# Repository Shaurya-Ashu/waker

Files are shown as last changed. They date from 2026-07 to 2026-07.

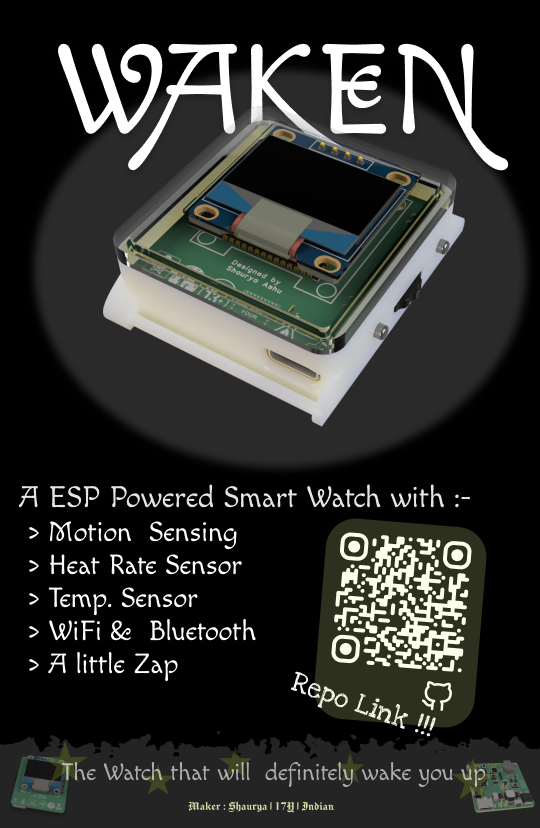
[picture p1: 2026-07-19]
IMG/Frame 7.png

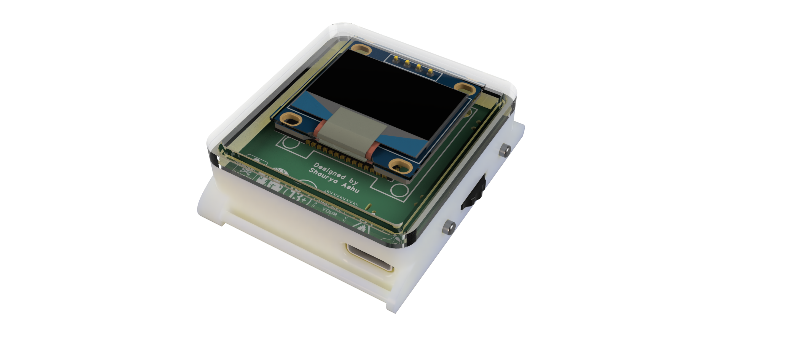
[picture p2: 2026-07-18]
CAD/IMG_1.png

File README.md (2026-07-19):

# waken
A ESP powered Smart watch which gives you a little zap to wake you up silently without disturbing anyone around you.

# why I built it ?
Ahhhh! I'm not crazy, I just sleep like a stone . So to get me up on time, I caught an idea why not make a watch which sits on my wrist and give me a little zap of 400V (\j) to wake me up . 

# Zine

 Frame 7

# Shematics 
I've used EasyEDA for design designing this project

Screenshot 2026-07-18 at 12 30 59 AM

 It has ESP32S3-WROON-1-N16R8 as the main brains , it has been built RTC and feature both Wi-Fi and Bluetooth with access to multiple GPIOs .

 Screenshot 2026-07-19 at 11 32 55 PM

 For tracking motion and physical activities like step count, etc. I've used MPU6500 which features both I2C & SPI interface. I've used I2C interface for this project.
 
Screenshot 2026-07-19 at 11 33 51 PM

 For sensing temperature I used MCP9808 which also offers I2C interface so its easy to wire all of them in signle bus 

 Screenshot 2026-07-19 at 11 35 23 PM

 The heart rate sensor is MAX30101 with I2C interface which offers optical pulse oximetry and heart-rate sensing .

 Screenshot 2026-07-19 at 11 37 22 PM

 To charge the lipo battery i have integrated a charging ic for 1s lipo and also integrated a load sharing circuit so that i can use teh device while charging .

 Screenshot 2026-07-19 at 11 39 22 PM

 To provide a constant supply of 3.3 V I am integrated a buck boost converter output of 3.3V @1.5A 
 
 Screenshot 2026-07-19 at 11 41 27 PM

 Now for that little zap i have used a simple fly back circuit with a couple inductor of scale 1:100 and IRLR7843 N chaneel mosfet to turn it on and off and a some massive 400v rated caps to store the build up with a series resistance of 150K ohm for safety .
 
 Screenshot 2026-07-19 at 11 44 28 PM

For Inputs and outputs we have 2 push buttons and a side scroll wheel with oled and buzzers as our output 

Screenshot 2026-07-19 at 11 46 19 PM

# PCB 
 I have used 4 layer configuration

Top layer:- signals and some components

Screenshot 2026-07-18 at 7 22 29 PM

First inner layer:- ground

Screenshot 2026-07-18 at 7 22 35 PM

Second inner layer:- VCC

Screenshot 2026-07-18 at 7 22 40 PM

Bottom layer:- signal and all other components

Screenshot 2026-07-18 at 7 22 23 PM

Important Note : I have not connected the ground of flyback with the rest of the circuit I will use a physical wire to connect when I receive a PCB.

FRONT

BACK

# CAD 

I have used fusion 360 student edition for designing the 3D case for this watch

It is a very simple case on which the PCB is screwed using two screws, and the top part is tucked in and glued 


# Assembly

Top Case

The pcb is screwed in 

1 step

# Firmware 
 I stated a very brief sample test code till now. When I will receive my PCB, then I will work on the rest of the firmware.

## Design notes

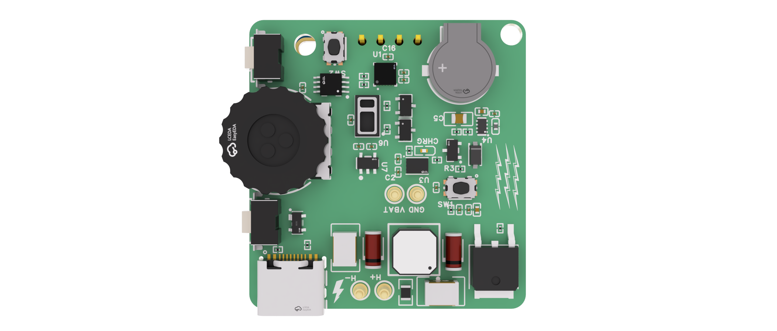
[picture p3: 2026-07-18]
CAD/BACK.png

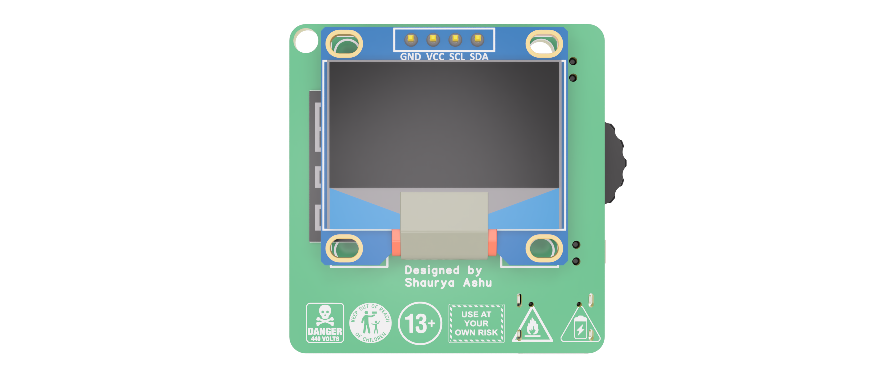
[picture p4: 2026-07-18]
CAD/FRONT.png

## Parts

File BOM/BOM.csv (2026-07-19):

S.No | Item Name | Description | Quantity | Price per Unit ($) | Total Price ($) | Purchase Link
1 | ESP32S3 | ESP32-S3-WROOM-1-N16R8 (WIRELM-SMD_ESP32-S3-WROOM-1) - Designators: BRAINS | 1 | 0.8198 | 0.8198 | https://jlcpcb.com/parts/componentSearch?searchTxt=C2913202
2 | MLT-9032 | MLT-9032 (BUZ-SMD_MLT-9032) - Designators: BUZZER1 | 1 | 0.0482 | 0.0482 | https://jlcpcb.com/parts/componentSearch?searchTxt=C194480
3 | 4.7uF | JDK063BBJ475MV-AT (C0201) - Designators: C1,C2,C13,C14 | 4 | 0.0093 | 0.0372 | https://jlcpcb.com/parts/componentSearch?searchTxt=C2880368
4 | 1uF | CL03A105MQ3CSNH (C0201) - Designators: C3 | 1 | 0.0010 | 0.0010 | https://jlcpcb.com/parts/componentSearch?searchTxt=C53067
5 | 22uF | JDK105CBJ226MV-F (C0402) - Designators: C4,C6 | 2 | 0.0245 | 0.0490 | https://jlcpcb.com/parts/componentSearch?searchTxt=C385994
6 | 47uF | GRM21BR60J476ME15L (C0805) - Designators: C5 | 1 | 0.0478 | 0.0478 | https://jlcpcb.com/parts/componentSearch?searchTxt=C77072
7 | 1uF | GRM033R60J105KEA2D (C0201) - Designators: C7 | 1 | 0.0066 | 0.0066 | https://jlcpcb.com/parts/componentSearch?searchTxt=C76929
8 | 100nF | GRM033R60J104KE19D (C0201) - Designators: C8,C9,C10,C11,C12,C15,C16 | 7 | 0.0004 | 0.0028 | https://jlcpcb.com/parts/componentSearch?searchTxt=C76928
9 | 470nF | C4532X7T2W474KT000N (C1812) - Designators: C17,C18 | 2 | 0.0984 | 0.1968 | https://jlcpcb.com/parts/componentSearch?searchTxt=C342626
10 | 16-213SDRC/S530-A3/TR8 | 16-213SDRC/S530-A3/TR8 (LED0402-R-RD) - Designators: CHRG | 1 | 0.0049 | 0.0049 | https://jlcpcb.com/parts/componentSearch?searchTxt=C71911
11 | B130LAW-7-F | B130LAW-7-F (SOD-123_L2.8-W1.8-LS3.7-RD) - Designators: D1 | 1 | 0.0406 | 0.0406 | https://jlcpcb.com/parts/componentSearch?searchTxt=C129191
12 | PRTR5V0U2X | PRTR5V0U2X (SOT-143-4_L2.9-W1.3-P1.92-LS2.4-BL) - Designators: D2 | 1 | 0.0098 | 0.0098 | https://jlcpcb.com/parts/componentSearch?searchTxt=C2827688
13 | SUF4007 | SUF4007 (DO-213AB_L5.0-W2.5-RD) - Designators: D3,D4 | 2 | 0.0148 | 0.0296 | https://jlcpcb.com/parts/componentSearch?searchTxt=C212757
14 | lipo battery | 1S 500MAH | 4 | 0.0234 | 0.0936 | https://makerbazar.in/products/kp-3-7v-500mah-lipo-battery-single-cell-lithium-polymer-battery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
15 | 1uH | LSCNB1005EET1R0MB (L0402) - Designators: L1 | 1 | 0.0548 | 0.0548 | https://jlcpcb.com/parts/componentSearch?searchTxt=C6653407
16 | LPR6235-752SMRC | LPR6235-752SMRC (IND-SMD_4P-L6.0-W6.0_LPR6235-752SMRC) - Designators: L2 | 1 | 1.1229 | 1.1229 | https://jlcpcb.com/parts/componentSearch?searchTxt=C7501749
17 | OLED Display 128x64 (I2C, SSD1315) | 0.96" OLED Display 128x64, I2C - Designator: OLED1 | 1 | 1.2448 | 1.2448 | https://jlcpcb.com/partdetail/HS-0_96_OLED_IIC/C5248080
18 | DMP1045U-HXY | DMP1045U-HXY (SOT-23-3_L2.9-W1.5-P1.90-LS2.6-BR) - Designators: Q1 | 1 | 0.0108 | 0.0108 | https://jlcpcb.com/parts/componentSearch?searchTxt=C22366440
19 | BSS138-7-F | BSS138-7-F (SOT-23-3_L2.9-W1.6-P1.90-LS2.8-BR) - Designators: Q2,Q3 | 2 | 0.0072 | 0.0144 | https://jlcpcb.com/parts/componentSearch?searchTxt=C40912
20 | IRLR7843-DO | IRLR7843-DO (TO-252-2_L6.6-W6.2-P4.57-LS10.1-BR-CW) - Designators: Q4 | 1 | 0.0311 | 0.0311 | https://jlcpcb.com/parts/componentSearch?searchTxt=C49208603
21 | 470Ω | RTT014700FTH (R0201) - Designators: R1 | 1 | 0.0003 | 0.0003 | https://jlcpcb.com/parts/componentSearch?searchTxt=C166182
22 | 10kΩ | RTT011002FTH (R0201) - Designators: R2 | 1 | 0.0002 | 0.0002 | https://jlcpcb.com/parts/componentSearch?searchTxt=C102684
23 | 100kΩ | CR0201FH1003G (R0201) - Designators: R3 | 1 | 0.0007 | 0.0007 | https://jlcpcb.com/parts/componentSearch?searchTxt=C100127
24 | 5.1kΩ | RC0201JR-075K1L (R0201) - Designators: R4,R5 | 2 | 0.0003 | 0.0006 | https://jlcpcb.com/parts/componentSearch?searchTxt=C163490
25 | 511kΩ | 0201WMF5113TEE (R0201) - Designators: R6 | 1 | 0.0002 | 0.0002 | https://jlcpcb.com/parts/componentSearch?searchTxt=C270342
26 | 91kΩ | RTT01913JTH (R0201) - Designators: R7 | 1 | 0.0002 | 0.0002 | https://jlcpcb.com/parts/componentSearch?searchTxt=C158299
27 | 10kΩ | RTT01103JTH (R0201) - Designators: R8,R15 | 2 | 0.0003 | 0.0006 | https://jlcpcb.com/parts/componentSearch?searchTxt=C102690
28 | 4.7kΩ | RC0201JR-074K7L (R0201) - Designators: R9,R10,R13,R14 | 4 | 0.0005 | 0.0020 | https://jlcpcb.com/parts/componentSearch?searchTxt=C142008
29 | 150kΩ | 0805W8J0154T5E (R0805) - Designators: R12 | 1 | 0.0003 | 0.0003 | https://jlcpcb.com/parts/componentSearch?searchTxt=C25619
30 | KMR223GLFG | KMR223GLFG (SW-SMD_5P-L4.2-W2.8-P1.60-LS4.6-TR) - Designators: SW1,SW2 | 2 | 0.1147 | 0.2294 | https://jlcpcb.com/parts/componentSearch?searchTxt=C221678
31 | K2-1845SA-D4SW-04 | K2-1845SA-D4SW-04 (KEY-SMD_K2-1845SA-D4SW-04) - Designators: SW3,SW4 | 2 | 0.0155 | 0.0310 | https://jlcpcb.com/parts/componentSearch?searchTxt=C128934
32 | MPU-6500 | MPU-6500 (QFN-24_L3.0-W3.0-P0.40-BL-EP) - Designators: U1 | 1 | 0.7820 | 0.7820 | https://jlcpcb.com/parts/componentSearch?searchTxt=C50278
33 | MCP73831T-2ACI/MC | MCP73831T-2ACI/MC (DFN-8_L3.0-W2.0-P0.50-BL-EP1.6) - Designators: U3 | 1 | 0.1493 | 0.1493 | https://jlcpcb.com/parts/componentSearch?searchTxt=C411870
34 | TPS631000DRLR | TPS631000DRLR (SOT-583-8_L2.1-W1.2-P0.50-LS1.6-BL) - Designators: U4 | 1 | 0.0779 | 0.0779 | https://jlcpcb.com/parts/componentSearch?searchTxt=C5219190
35 | MCP9808-E/MS | MCP9808-E/MS (MSOP-8_L3.0-W3.0-P0.65-LS4.9-BL) - Designators: U5 | 1 | 0.3306 | 0.3306 | https://jlcpcb.com/parts/componentSearch?searchTxt=C94847
36 | MAX30101EFD+T | MAX30101EFD+T (OESIP-14_L5.6-W3.3-P0.80-TL) - Designators: U6 | 1 | 1.5619 | 1.5619 | https://jlcpcb.com/parts/componentSearch?searchTxt=C2859066
37 | TPS78918DBVR | TPS78918DBVR (SOT-23-5_L2.9-W1.6-P0.95-LS2.8-BR) - Designators: U7 | 1 | 0.2703 | 0.2703 | https://jlcpcb.com/parts/componentSearch?searchTxt=C2873122
38 | SIQ-02FVS3 | SIQ-02FVS3 (SW-SMD_SIQ-02FVS3_1) - Designators: U8 | 1 | 0.6364 | 0.6364 | https://jlcpcb.com/parts/componentSearch?searchTxt=C2925423
39 | USB-310-B-SU | USB-310-B-SU (USB-C-SMD_20P-P0.50-L7.4-W8.9) - Designators: USB | 1 | 0.0330 | 0.0330 | https://jlcpcb.com/parts/componentSearch?searchTxt=C309347
40 | 3D Printing (Case) | 3D printed enclosure/case for the device | 1 | 5.00 | 5.00 | https://jlcpcb.com/3d-printing
41 | PCB Manufacturing + PCBA Service | 5x PCBs manufactured, 2 of which assembled (PCBA) via JLCPCB | 1 | 100.00 | 100.00 | https://jlcpcb.com/quote
 |  |  |  | GRAND TOTAL | $112.97

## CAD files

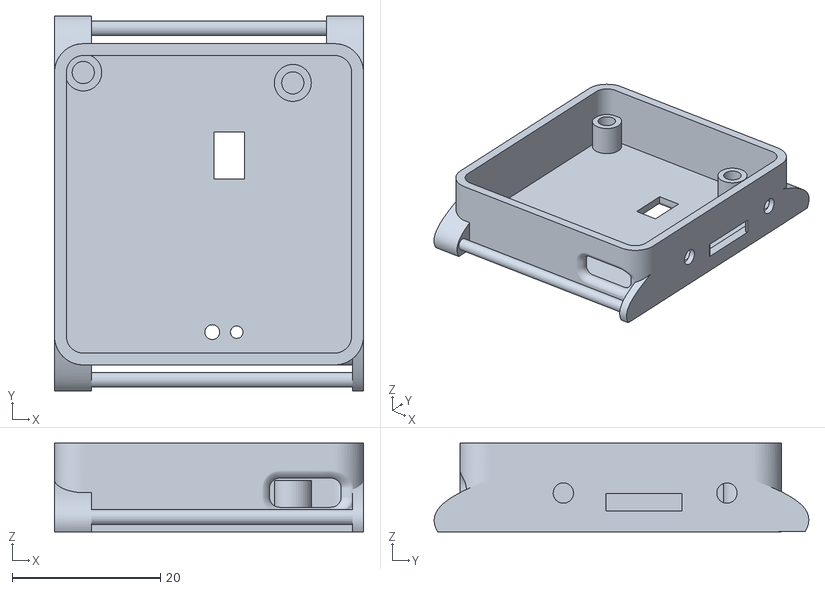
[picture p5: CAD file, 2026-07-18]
CAD/Bottom_Case.stl
41.7 x 50.6 x 12.0

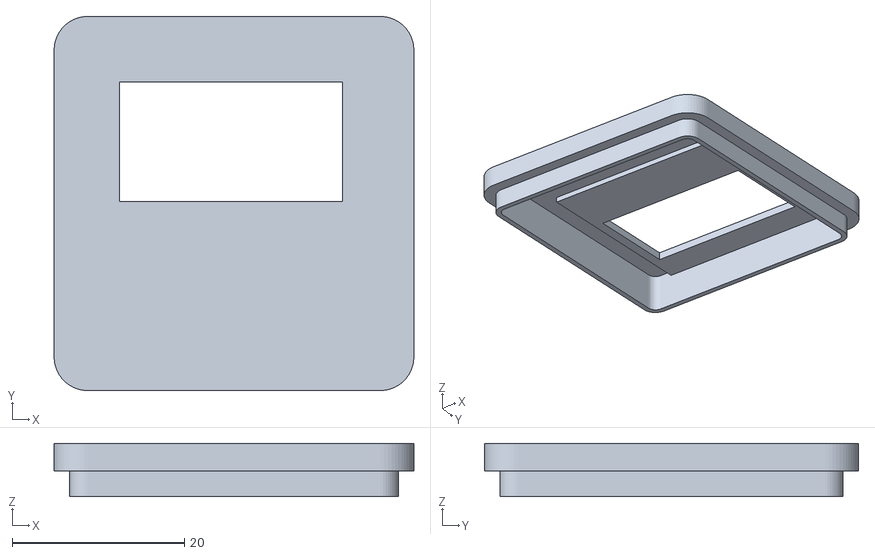
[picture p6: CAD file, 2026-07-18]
CAD/Upper_Case.stl
41.7 x 43.4 x 6.19

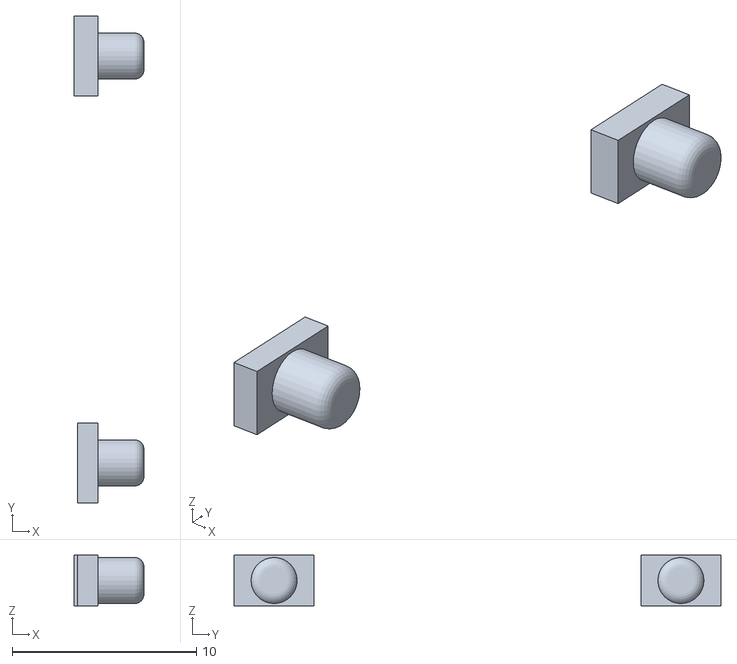
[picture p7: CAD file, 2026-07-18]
CAD/buttons.stl
3.80 x 26.4 x 2.75

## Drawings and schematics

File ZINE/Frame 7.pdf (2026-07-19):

# WAKEN

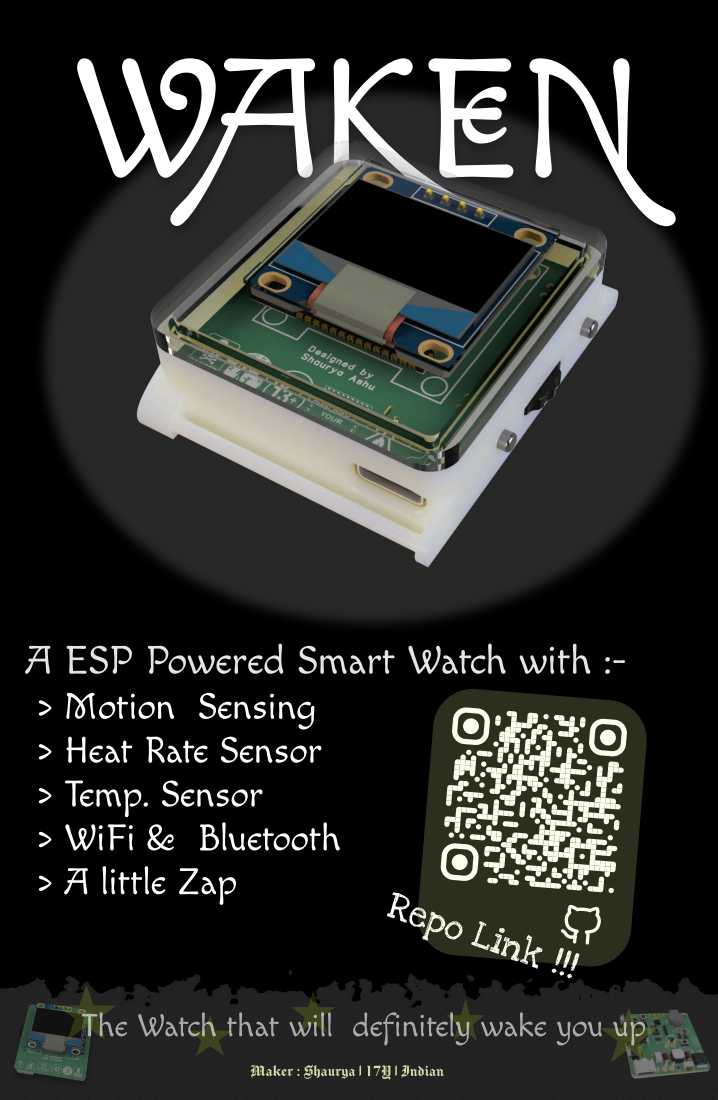
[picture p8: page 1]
> A little Zap; Repo Link !!!

A ESP Powered Smart Watch with :-
> Motion Sensing
> Heat Rate Sensor
> Temp. Sensor
> WiFi & Bluetooth

The Watch that will definitely wake you up

Maker : Shaurya | 17Y | Indian

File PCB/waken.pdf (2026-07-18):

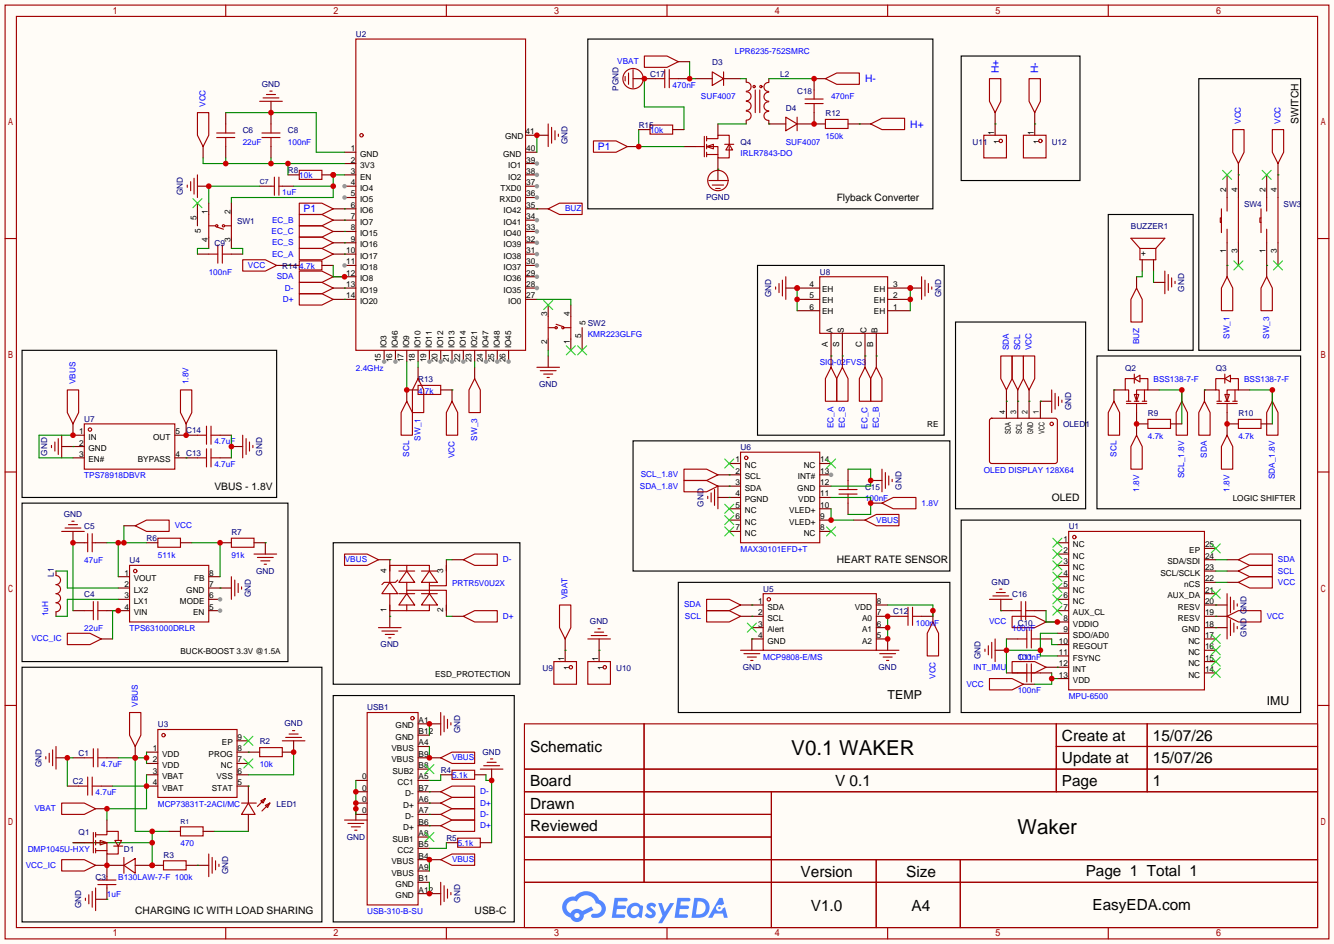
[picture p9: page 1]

VLED+ 10 VDD 11 GND 12 INT# 13 NC 14

Schematic | V0.1 WAKER | Create at | 15/07/26

Update at | 15/07/26

Board | V 0.1 | Page | 1
Drawn | | Waker
Reviewed

Version | Size | Page 1 Total 1
V1.0 | A4 | EasyEDA.com

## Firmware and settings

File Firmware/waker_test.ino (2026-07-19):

#include <Wire.h>
#include <Adafruit_GFX.h>
#include <Adafruit_SSD1306.h>

#define SDA_PIN 9
#define SCL_PIN 10
#define INT_IMU_PIN 35
#define SW1_PIN 37
#define SW3_PIN 36
#define EC_A_PIN 18
#define EC_B_PIN 15
#define EC_C_PIN 16
#define EC_S_PIN 17
#define BUZ_PIN 41
#define PGND_PIN 38

#define OLED_ADDR 0x3C
#define MPU_ADDR 0x68
#define MAX30101_ADDR 0x57
#define MCP9808_ADDR 0x18

Adafruit_SSD1306 display(128, 64, &Wire, -1);

bool i2cPresent(uint8_t addr) {
  Wire.beginTransmission(addr);
  return Wire.endTransmission() == 0;
}

uint8_t readReg(uint8_t addr, uint8_t reg) {
  Wire.beginTransmission(addr);
  Wire.write(reg);
  Wire.endTransmission(false);
  Wire.requestFrom(addr, (uint8_t)1);
  if (Wire.available()) return Wire.read();
  return 0xFF;
}

void i2cScan() {
  Serial.println("I2C SCAN:");
  for (uint8_t addr = 1; addr < 127; addr++) {
    if (i2cPresent(addr)) Serial.printf("Found 0x%02X\n", addr);
  }
}

void testOLED() {
  if (!display.begin(SSD1306_SWITCHCAPVCC, OLED_ADDR)) {
    Serial.println("OLED: FAIL");
    return;
  }
  display.clearDisplay();
  display.setTextSize(1);
  display.setTextColor(SSD1306_WHITE);
  display.setCursor(0, 0);
  display.println("WAKER TEST OK");
  display.display();
  Serial.println("OLED: PASS");
}

void testIMU() {
  if (!i2cPresent(MPU_ADDR)) { Serial.println("IMU: NOT FOUND"); return; }
  uint8_t who = readReg(MPU_ADDR, 0x75);
  Serial.printf("IMU WHOAMI=0x%02X %s\n", who, who == 0x70 ? "PASS" : "FAIL");
  Serial.printf("INT_IMU pin state: %d\n", digitalRead(INT_IMU_PIN));
}

void testHR() {
  if (!i2cPresent(MAX30101_ADDR)) { Serial.println("HR: NOT FOUND"); return; }
  uint8_t id = readReg(MAX30101_ADDR, 0xFF);
  Serial.printf("HR PARTID=0x%02X %s\n", id, id == 0x15 ? "PASS" : "FAIL");
}

void testTemp() {
  if (!i2cPresent(MCP9808_ADDR)) { Serial.println("TEMP: NOT FOUND"); return; }
  Wire.beginTransmission(MCP9808_ADDR);
  Wire.write(0x05);
  Wire.endTransmission(false);
  Wire.requestFrom(MCP9808_ADDR, (uint8_t)2);
  if (Wire.available() == 2) {
    uint8_t msb = Wire.read();
    uint8_t lsb = Wire.read();
    msb &= 0x1F;
    float temp;
    if (msb & 0x10) {
      msb &= 0x0F;
      temp = 256 - (msb * 16.0 + lsb / 16.0);
    } else {
      temp = msb * 16.0 + lsb / 16.0;
    }
    Serial.printf("TEMP=%.2fC PASS\n", temp);
  } else {
    Serial.println("TEMP: READ FAIL");
  }
}

void testBuzzer() {
  tone(BUZ_PIN, 2000, 200);
  delay(300);
  Serial.println("BUZZER: PULSED");
}

void testButtons() {
  Serial.printf("SW1:%d SW3:%d EC_A:%d EC_B:%d EC_C:%d EC_S:%d\n",
    !digitalRead(SW1_PIN), !digitalRead(SW3_PIN),
    !digitalRead(EC_A_PIN), !digitalRead(EC_B_PIN),
    !digitalRead(EC_C_PIN), !digitalRead(EC_S_PIN));
}

void testFlyback() {
  ledcAttach(PGND_PIN, 20000, 8);
  ledcWrite(PGND_PIN, 20);
  delay(50);
  ledcWrite(PGND_PIN, 0);
  Serial.println("FLYBACK: GATE PULSED (verify with scope, no load connected)");
}

void setup() {
  Serial.begin(115200);
  delay(1000);
  Wire.begin(SDA_PIN, SCL_PIN);

  pinMode(INT_IMU_PIN, INPUT);
  pinMode(SW1_PIN, INPUT_PULLUP);
  pinMode(SW3_PIN, INPUT_PULLUP);
  pinMode(EC_A_PIN, INPUT_PULLUP);
  pinMode(EC_B_PIN, INPUT_PULLUP);
  pinMode(EC_C_PIN, INPUT_PULLUP);
  pinMode(EC_S_PIN, INPUT_PULLUP);
  pinMode(BUZ_PIN, OUTPUT);

  i2cScan();
  testOLED();
  testIMU();
  testHR();
  testTemp();
  testBuzzer();
  testFlyback();
}

void loop() {
  testButtons();
  delay(500);
}
